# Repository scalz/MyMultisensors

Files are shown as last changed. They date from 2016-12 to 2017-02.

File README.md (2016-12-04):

# MyMultisensors

MyMultisensors is a compact multi sensors capable node for your/my home automation.
Optmized for very low power, ambiant sensors node, battery powered and wireless, i can easily add in each room. 

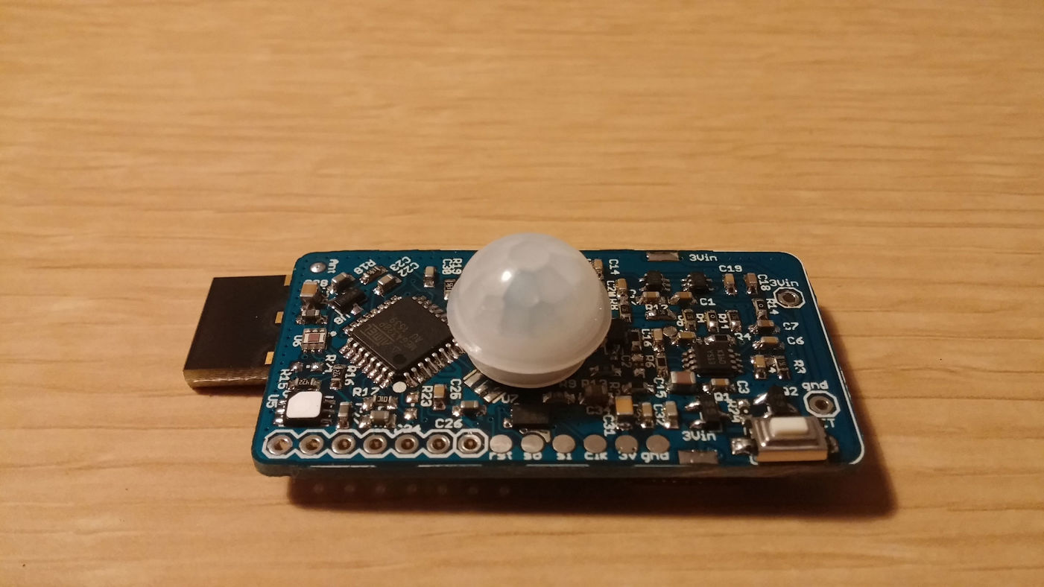
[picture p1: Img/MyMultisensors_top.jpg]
MyMultisensors top
 

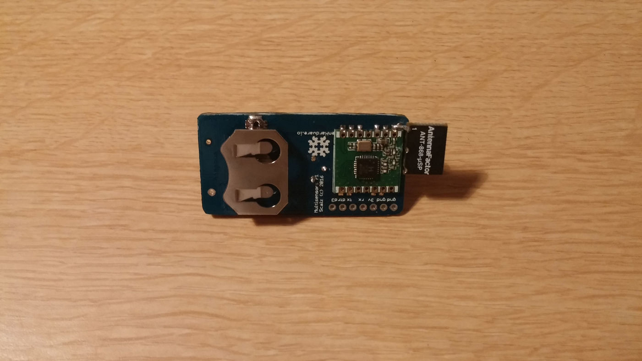
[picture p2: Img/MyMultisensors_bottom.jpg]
MyMultisensors bottom
 

I have to say, this is one of my favorite board! well, you think i'm biased :) a bit true ;)
But the truth is i've never seen the same board before (with my requirements) or i wouldn't have made it!

I put multiple "constraints" on myself to get the best of what i can do myself imho.
- Most common sensors used indoor : Temperature/Humidity/Motion/Ambiant Light/Door Contact. Using the best low power sensors i know.
- Entry level MCU so noobs can easily play with it (well known 328p)
- Tiny so i can reuse the board if i need a simple motion or door contact device. One pcb allows multiple devices. Standardisation of main ambiant indoor devices with box.
- Thin, like a simple temperature/humidity tag. So coincell 2032. Depending on the scenario, I need to be able to change the battery holder for CR2032/CR2450/AAA.
- Very very low power. 2years min with a simple good brand CR2032 (depending of usecase). Choosing the right parts for low power.
- Mysensors Wireless programming and Signing/Authentication features are mandatory for a device which can do some security tasks like Motion detection.
- RFM69 and its nice range even with the low power RFM69CW version onboard. I'm finalizing the nrf24 version because it's a nice board, that would be too bad for nrf24 user ;)
- I also tried to take care of the routing; and to have strong, unbroken GND plane as it is very important to get best range, especially with monopole wire I'm using (it's also possible to use a planar pcb ant though) 
- and not the least constraint! I've tried to keep cost reasonable regarding if i would buy it, or people etc..

As everything is customizable, the choice of the battery or the custom pcb size (compact), the easy and quite common way is printing a custom box..

I think i've "almost" achieved my goals :)

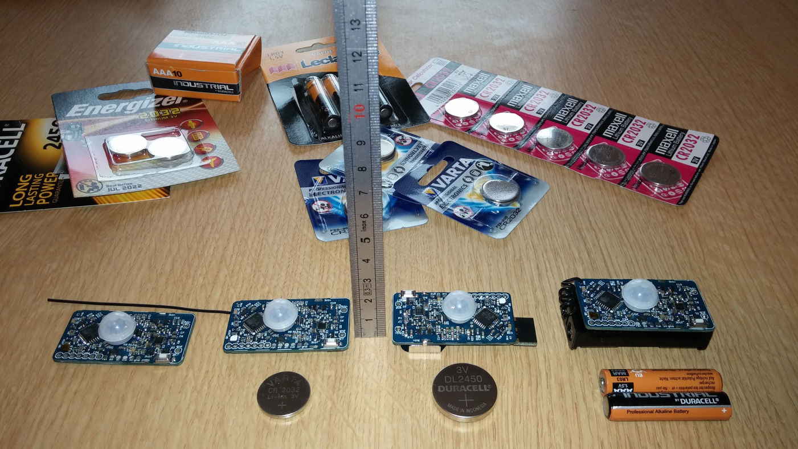
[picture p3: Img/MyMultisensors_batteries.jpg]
MyMultisensors batteries
 

We can see this is possible to use different kind of battery, and different antennas (wire or planar pcb).

###General specs
------

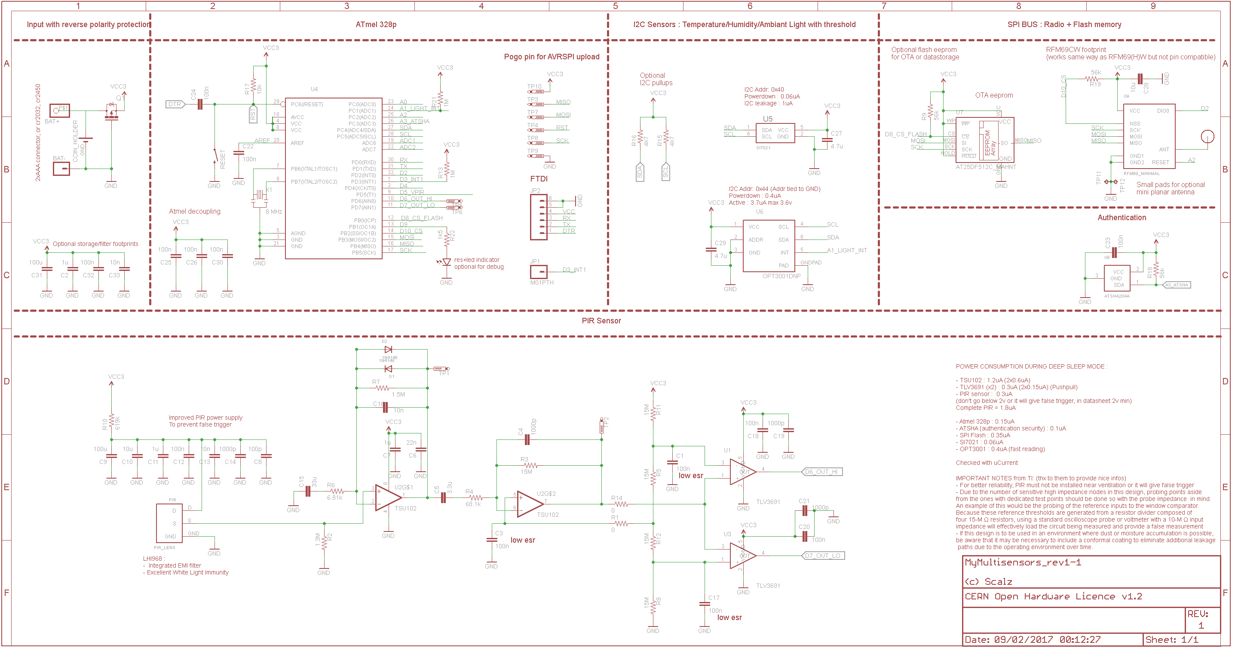
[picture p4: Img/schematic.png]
schematic
 

|Specs|  |
|---|---|---|
|Size |49*25.4 (mm) |
| MCU | Atmel328p TQFP 150nA deep sleep|
| Radio | RFM69CW 100nA in deep sleep, NRF24 is coming |
| Authentication security | ATSHA204A chip footprint 150nA in deep sleep|
| OverTheAir Wireless programming | SPI flash eeprom footprint 200nA in deep sleep |
| Temperature/Humidity | SI7021 60nA in deep sleep |
| Ambiant Light Lux | OPT3001 300nA in deep sleep, with footprint for optional pullup resistor |
| Motion detection | LHI968 good quality/price, with its circuit, active 1.6uA |
| Door contact | footprint for soldering an optional pullup resistor >1M | 
| Indicator Led | Yes, on D9 |
| Extension connector | FTDI + D3 for connecting Door contact | 
| Pogo pins | AVRSPI programming |
| Battery connectors | CR2032 240mAh, CR2450 500mAh, 2xAAA 1200mAh |
| Power Supply | Reverse-polarity protection. 3V3 max |

####Onboard safety

Onboard, there is a reverse polarity protection. But for power savings, better efficiency etc .. there is no voltage regulator. So it's possible to use others batteries, or ftdi of course, but the max input voltage is 3.3V max.

####Extension Connectors

For simplicity, and trying to boost my assembling process (i use reflow), i'm using pogopins. I've done a simple adapter like this..
- AVRSPI : for burning the bootloader. Here i'm using the Sensebender Micro Atmel 328p Internal 8Mhz BOD 1.8V, in Boards Manager/Mysensors boards
- FTDI : for uploading the sketch. Without an optimized sketch, no big power savings. it's hw/sw.. still work in progress, i'll never be happy :)

####Power consumption, what can we expect ?

Power consumption has been checked with uCurrent Gold + old voltcraft vc506..

Measurement done with PIR enabled, sensors sleeping but without spiflash ic nor Door contact

| Mode | Varta coincell CR2032 | Duracell 2xAAA |
|---|---|---|---|
|MCU in deep sleep, interrupt on change |4uA | 3uA|
|MCU in deep sleep, interrupt on change Wdt Enabled | 8uA | 11uA|
|MCU running 1Mhz | 732uA | 737uA|

Few simple maths because battery lifetime can change for multiple reasons (battery brand, internal resistance of coincell etc.). I won't explain everything here.

Still important to remember, is we can't expect to have the complete 240mAh of a coincell. Better bet on 200mAh, for a good quality coincell. For bad quality, it can be worse! Bad clone coincell can have only 50% of usable energy! Try clone and good brands, you will see what i mean ;) it's up to you if you want to spend your time to replace batteries :)

As RFM69 radio power consumption is low during sleep mode, no need to disable it, so it allows to use listenmode and wakeup from mcu from deep sleep for instance.

Say a power consumption of 5uA during sleep mode, the PIR is enabled of course, but not triggered (note it is possible to disable the PIR motion sensor to save power).
And our RFM69 needs 30mA during 40ms. Rough estimation!  it does not spend this whole 40ms transmitting of course! And with automatic RSSI and power level control, the radio can consumes less power in TX.
On other hand, it does not take in account the signing time if feature is used.

So 30mA for 40ms, say 10 motions detection/hour, give us a theoretical estimation of 2.33years.
Not so bad..but the node can last a lot more if the software is well optimized and flexible to let user to set dynamically during days, the sensibility and motion detection settings etc..

####Arduino Pin description

|Arduino sketch define| Arduino Pin | description |
|---|---|---|
| MY_OTA_FLASH_SS | 8 | EEprom CS pin |
| ATSHA204_PIN | 17 | ATSHA204A SOT23 pin (for authentication) |
| PIR_INT_PINH  | 6 | PIR motion sensor pin H |
| PIR_INT_PINL | 7 | PIR motion sensor pin L |
| MYNODE_LED_PIN | 9 | Status led pin |
| REED_SWITCH_PIN | 3 | Reed switch pin interrupt on int1 D3 |
| AMBIANT_LIGHT_INT | A1  | Ambiant light sensor pin interrupt |

### Some ideas for the Mysensors sketch
------

|General Node settings | Default Settings | Notes|
|---|---|---|---|
| MY_NODE_NAME | MYS_MOTION| Node/sketch name|
|MY_DEBUG|1.0| General Level Mysensors Debug messages. Comment it to save memory!|
|MY_DEBUG_SKETCH|1.0|Sketch Level Debug messages. Comment it to save memory!|
|MY_NODE_ID|AUTO| AUTO or set a fixed ID|
|PARENT_NODE_ID|| Uncomment it and set your parent node id if needed|
|RELEASE |1.0| Sketch version|
|MY_BAUD_RATE|38400||
|isMetric |true| true/false|
|//atsha204Class sha204(sha204Pin);||Uncomment to enable signing|
|//MY_OTA_FIRMWARE_FEATURE||Uncomment to enable OTA wireless programming|
|MY_RFM69_NETWORKID|100| Uncomment and set your preferred network id|
|MY_RFM69_ATC_TARGET_RSSI_DBM|-80| Uncomment and set your preferred RSSI target|
|LIGHT_H_LIMIT|100|High Threshold for Ambiant light sensor|
|LIGHT_L_LIMIT|20|Low Threshold for Ambiant light sensor|
|LIGHT_TRANSMIT_THRESHOLD|50| Delta needed for updating Ambiant sensor to controller|
|HUMI_TRANSMIT_THRESHOLD|5|Delta needed for updating Humidity sensor to controller|
|TEMP_TRANSMIT_THRESHOLD|1|Delta needed for updating Temperature sensor to controller|
|FORCE_TRANSMIT_INTERVAL|10| Intervalle time between transmit update|
|BATTERY_USB| |Uncomment if using ftdi, for batt voltage reading|
|BATTERY_VARTA_2032| |Uncomment if using CR2032, for batt voltage reading|
|BATTERY_DURAC_2450| |Uncomment if using CR2450, for batt voltage reading|
|BATTERY_DURAC_IND_2AAA| |Uncomment if using 2xAAA, for batt voltage reading|

|MyPirHelper.h | Default Settings | Notes |
|---|---|---|---|
| PIR_SETTLE_TIME | 20000| in milliseconds/ better 30000. Waiting for PIR settling at node init|
| PIR_DEFAULT_PULSES | 8| Programmable pulse counter : 1... 255 pulses but for 255 pulses you'll need to dance for a nice motion :)|
| PIR_DEFAULT_WINDOWTIME | 1| Window time : 0 to 3.  Range: 8s... 16s.  Time in sec = 8 * (value+1)|
| PIR_DEFAULT_CANCELTIME | 2| Cancel Time : 0 to 10. Range: 8s... 80s.  Time = 8 * (value+1)|
| PIR_DEFAULT_BLINDTIME | 2| Blind Time  : 0 to 15. Range: 0s... 120s. Time = 8 * value|

All these infos can be found in the source files.

####External Libraries needed
- Opt3001      : https://github.com/node-it/EnvironOne/blob/master/src/Opt3001.h
- SI7021       : from Marcus Sorensen <marcus@electron14.com> 

####From the controller view

These are the CHILD_IDs used for sensors, or for dynamic settings.

|CHILD NODE ID/CMD | Default ID | Notes|
|---|---|---|---|
| CHILD_ID_PIR | 1|PIR sensor |
| CHILD_ID_PIR_EN | 2|Enable PIR |
| CHILD_ID_TEMP  | 3|Temperature sensor|
| CHILD_ID_HUM | 4|Humidity Child node ID|
| CHILD_ID_LIGHT  | 5|Ambiant light Child node ID|
| CHILD_ID_DOOR | 6|Door reed switch|
| CMID_FULL | 10|Command from controller with all params below in one tx. below is for debug..|
| CMID_PULSES | 11|Command from controller to set PIR number of pulse for windows time  |
| CMID_WINDOWTIME | 12|Command from controller to set PIR window time  |
| CMID_BLINDTIME | 13|Command from controller to set PIR blind time|
| CMID_CANCELTIME | 14|Command from controller to set PIR cancel time|
| CMID_EN_LIGHT | 15|Command from controller to enable Light sensor threshold|
| CMID_LIGHT_MODE | 16|Command from controller to set Light sensor special mode (enable pir at certain light level only...)|
| CMID_LIGHT_H  | 17|Command from controller to set Light sensor high threshold |
| CMID_LIGHT_L | 18|Command from controller to set Light sensor low threshold |
| CMID_LIGHT_DELTA | 19|Command from controller to set difference of lux for update controller |
| CMID_TRANSMIT_INTERVAL | 20|Command from controller to set time between sensor updates|
| CMID_TH_DELTA | 21|Command from controller to set difference of temp/hum needed for update controller |
| CMID_EN_LED  | 22|Command from controller to set led|

###Known issues
------ 

###TODO
------
- improve sketch

###Donations
------

I'm trying to make opensource projects. I do this for free and sharing spirit. I don't do ads etc..
But if you think information here is worth of some money, or want to reward me, feel free to send any amount through paypal.

  

Or you can also order pcb here :
I will earn a little percentage that will allow me to order proto pcb and share more fun design.

Or pay me a protein smoothie if you see me! oh well, a beer is ok too :)

### Contributors
------
Always special thanks to:
- Mysensors Team for its great work
- Adafruit, Sparkfun, TI, Atmel etc.. for all educational infos they share

###Links, reference and license** 
------
- https://www.openhardware.io/view/75/MyMultisensors
- http://www2.st.com/content/ccc/resource/technical/document/application_note/b8/84/29/41/21/00/44/41/DM00096551.pdf/files/DM00096551.pdf/jcr:content/translations/en.D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
- http://www.ti.com/lit/ug/tiduau1a/tiduau1a.pdf

Copyright Scalz (2016). released under the CERN Open Hardware Licence v1.2

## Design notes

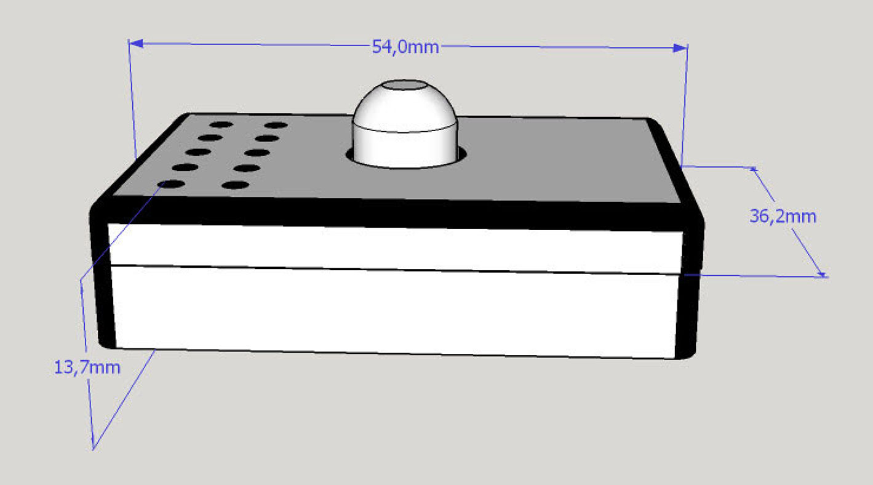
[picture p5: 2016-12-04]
Img/MyMultisensors_custombox_temp.jpg

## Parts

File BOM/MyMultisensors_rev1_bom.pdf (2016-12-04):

Parts | Qty Don't Put
Opt

Value

C1, C3, C12, C17, C18, C20, C22, C23, C25, C26 | 10 | | 100n
C30, C32, C33 | 12 | X
C4, C14, C19, C21 | 4 | | 1000p
C5 | 1 | | 3.3u
C6 | 1 | | 22n
C7, C11 | 2 | | 1u
C8 | 1 | | 100p
C13, C16 | 2 | | 10n
C27, C29 | 2 | | 4.7u
C2 | 1 | | 1u
C24 | 1 | | 100n
C9, C31 | 2 | | 100u
C10, C28 | 2 | | 10u
C15 | 1 | | 33u
D1, D2 | 2 | | 1N4148
D3 | 1 | | Red LED
Q1 | 1 | | CJ2305
R1, R14 | 2 | | 0
R2 | 1 | | 1.3M
R3, R5, R8, R11, R12 | 5 | | 15M
R4 | 1 | | 68.1k
R6 | 1 | | 6.81k
R7 | 1 | | 1.5M
R9, R18, R19 | 3 | | 56k
R10 | 1 | | 619k
R13, R21 | 2 | X | 1M
R15, R16 | 2 | | 4k7
R22 | 1 | | 1k5
R17 | 1 | | 10k
U1, U3 | 2 | | TLV3691IDCKR
U2 | 1 | | TSU102IST
U4 | 1 | | ATMEGA328P-AU
U5 | 1 | | SI7021-A20-GM1
U6 | 1 | | OPT3001DNPR
U7 | 1 | | AT25DF512C-MAHN-T
U8 | 1 | | ATSHA204A-STUCZ-T
U9 | 1 | | RFM69CW
RESET | 1 | | 1101NE
PIR | 1 | | LHI968
X1 | 1 | | 8 MHz
COIN_HOLDER | 1
JP2 | 1

Notes about optional parts:
- Some capa are optional. Footprints is there. For stability or more buffer.
- Resistors are for optional Reedswitch and optional Lux sensor Thresholds. Solder them if needed only or power consumption can increase

Package | Description | MPN
0603 | Capacitor
0603 | Capacitor
0603 | Capacitor
0603 | Capacitor
0603 | Capacitor
0603 | Capacitor
0603 | Capacitor
0603 | Capacitor
0603 | Capacitor
0805 | Capacitor
0805 | Capacitor
0805 | Capacitor
0805 | Capacitor
0805 | Capacitor
SOD-123 | Diode
0805 | LED
SOT23-3 | P-Channel MOSFET
0603 | Resistor
0603 | Resistor
0603 | Resistor
0603 | Resistor
0603 | Resistor
0603 | Resistor
0603 | Resistor
0603 | Resistor
0603 | Resistor
0603 | Resistor
0603 | Resistor
0805 | Resistor
SC70-5 | Comparator | 595-TLV3691IDCKR
MINI_SO8 | Dual Opamp | 511-TSU102IST (http://www.mouser.fr/ProductDetail/STMicroelectronics/TSU102IST/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)
TQFP32 | Atmel 8bit 328P TQFP32
DFN6 | Temp/Hum sensor | 634-SI7021-A20-GM1
OPT3001DNP | Lux sensor | 595-OPT3001DNPR
AT25DF512C_MAHNT SPI Flash | 988-AT25DF512CMAHN-T
SOT23-3 | Signing IC | 566-ATSHA204ASTUCZ-T
RFM69CW | Hoperf radio
| Tactile Switch 1101NE
TO5 | PIR sensor
RESONATOR-SMD | Resonator
Coincell Holder | CR2032/2450 footprints
1X06 | Pinheader

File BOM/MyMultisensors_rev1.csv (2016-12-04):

Parts | Qty | Don't Put Opt | Value | Package | Description | MPN
C1, C3, C12, C17, C18, C20, C22, C23, C25, C26 | 10 |  | 100n | 0603 | Capacitor
C30, C32, C33 | 12 | X |  | 0603 | Capacitor
C4, C14, C19, C21 | 4 |  | 1000p | 0603 | Capacitor
C5 | 1 |  | 3.3u | 0603 | Capacitor
C6 | 1 |  | 22n | 0603 | Capacitor
C7, C11 | 2 |  | 1u | 0603 | Capacitor
C8 | 1 |  | 100p | 0603 | Capacitor
C13, C16 | 2 |  | 10n | 0603 | Capacitor
C27, C29 | 2 |  | 4.7u | 0603 | Capacitor
C2 | 1 |  | 1u | 0805 | Capacitor
C24 | 1 |  | 100n | 0805 | Capacitor
C9, C31 | 2 |  | 100u | 0805 | Capacitor
C10, C28 | 2 |  | 10u | 0805 | Capacitor
C15 | 1 |  | 33u | 0805 | Capacitor
D1, D2 | 2 |  | 1N4148 | SOD-123 | Diode
D3 | 1 |  | Red LED | 0805 | LED
Q1 | 1 |  | CJ2305 | SOT23-3 | P-Channel MOSFET
R1, R14 | 2 |  | 0 | 0603 | Resistor
R2 | 1 |  | 1.3M | 0603 | Resistor
R3, R5, R8, R11, R12 | 5 |  | 15M | 0603 | Resistor
R4 | 1 |  | 68.1k | 0603 | Resistor
R6 | 1 |  | 6.81k | 0603 | Resistor
R7 | 1 |  | 1.5M | 0603 | Resistor
R9, R18, R19 | 3 |  | 56k | 0603 | Resistor
R10 | 1 |  | 619k | 0603 | Resistor
R13, R21 | 2 | X | 1M | 0603 | Resistor
R15, R16 | 2 |  | 4k7 | 0603 | Resistor
R22 | 1 |  | 1k5 | 0603 | Resistor
R17 | 1 |  | 10k | 0805 | Resistor
U1, U3 | 2 |  | TLV3691IDCKR | SC70-5 | Comparator | 595-TLV3691IDCKR
U2 | 1 |  | TSU102IST | MINI_SO8 | Dual Opamp | 511-TSU102IST
U4 | 1 |  | ATMEGA328P-AU | TQFP32 | Atmel 8bit 328P TQFP32
U5 | 1 |  | SI7021-A20-GM1 | DFN6 | Temp/Hum sensor | 634-SI7021-A20-GM1
U6 | 1 |  | OPT3001DNPR | OPT3001DNP | Lux sensor | 595-OPT3001DNPR
U7 | 1 |  | AT25DF512C-MAHN-T | AT25DF512C_MAHNT | SPI Flash | 988-AT25DF512CMAHN-T
U8 | 1 |  | ATSHA204A-STUCZ-T | SOT23-3 | Signing IC | 566-ATSHA204ASTUCZ-T
U9 | 1 |  | RFM69CW | RFM69CW | Hoperf radio
RESET | 1 |  | 1101NE |  | Tactile Switch 1101NE
PIR | 1 |  | LHI968 | TO5 | PIR sensor
X1 | 1 |  | 8 MHz | RESONATOR-SMD | Resonator
COIN_HOLDER | 1 |  |  | Coincell Holder | CR2032/2450 footprints
JP2 | 1 |  |  | 1X06 | Pinheader
Notes about optional parts: - Some capa are optional. Footprints is there. For stability or more buffer. - Resistors are for optional Reedswitch and optional Lux sensor Thresholds. Solder them if needed only or power consumption can increase

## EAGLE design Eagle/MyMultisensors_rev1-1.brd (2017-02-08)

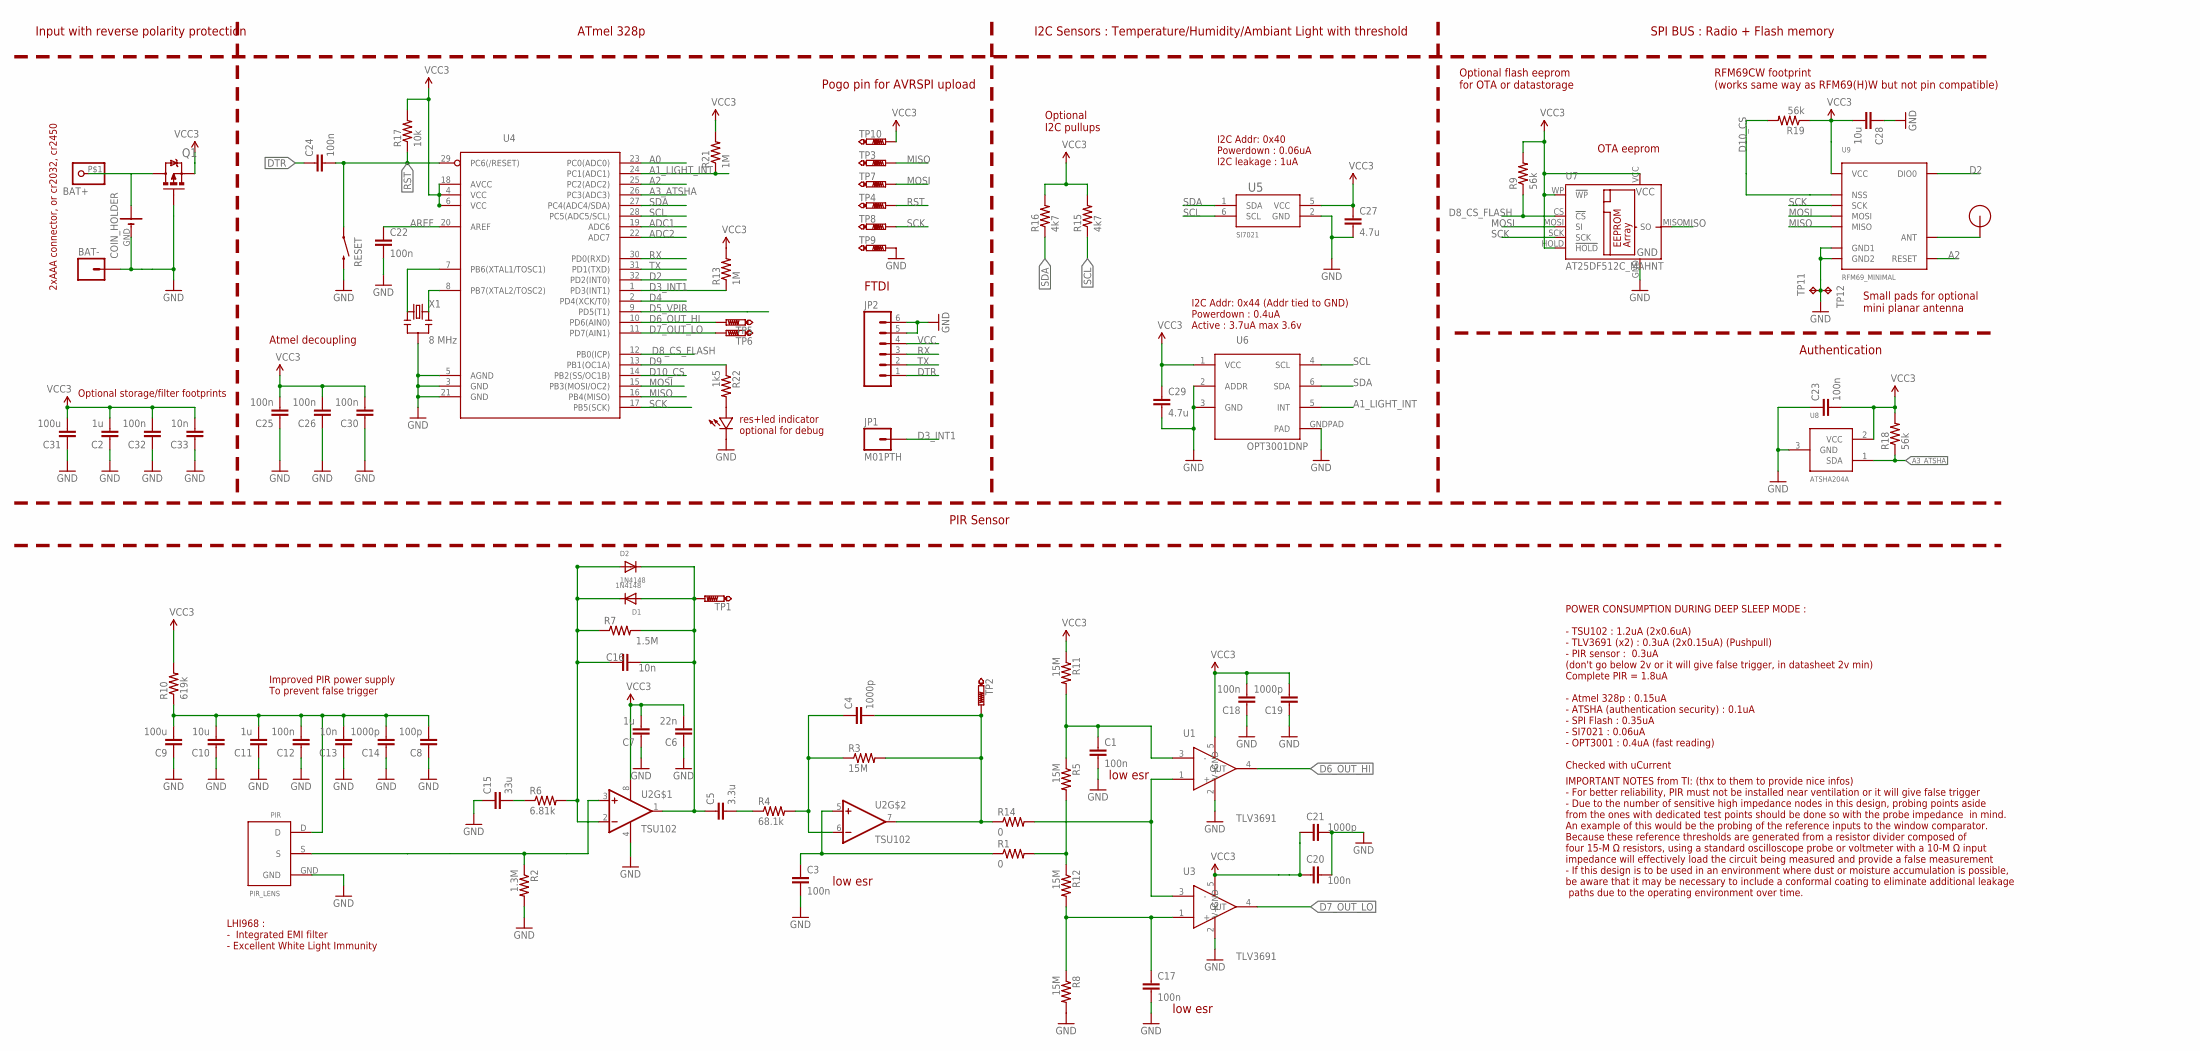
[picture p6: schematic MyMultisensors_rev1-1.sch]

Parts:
ANT: RFM12B_ANTENNA; RFM12B-ANTENNA
BAT+: PINHD-1X1TOP; 1X01_ONESIDE
BAT-: M01PTH; 1X01
C1, C3, C12, C17, C18, C20, C22, C23, C25, C26, C30, C32: 100n; 0603-CAP
C2: 1u; 0805-CAP
C4, C14, C19, C21: 1000p; 0603-CAP
C5: 3.3u; 0603-CAP
C6: 22n; 0603-CAP
C7, C11: 1u; 0603-CAP
C8: 100p; 0603-CAP
C9, C31: 100u; 0805-CAP
C10, C28: 10u; 0805-CAP
C13, C16, C33: 10n; 0603-CAP
C15: 33u; 0805-CAP
C24: 100n; 0805-CAP
C27, C29: 4.7u; 0603-CAP
COIN_HOLDER: CR2450_H_LOWCOSTVERTICAL_WITH_MILL; CR2450H_LOWCOST2
D1, D2: 1N4148; SOD-123
D3: LED0805; 0805-LED
JP1: M01PTH; 1X01
JP2: M06SIP; 1X06
PIR: PIR_LENS
Q1: SI2399DS-T1-GE3; SOT95P237X112-3N
R1, R14: 0; 0603-RES
R2: 1.3M; 0603-RES
R3, R5, R8, R11, R12: 15M; 0603-RES
R4: 68.1k; 0603-RES
R6: 6.81k; 0603-RES
R7: 1.5M; 0603-RES
R9, R18, R19: 56k; 0603-RES
R10: 619k; 0603-RES
R13, R21: 1M; 0603-RES
R15, R16: 4k7; 0603-RES
R17: 10k; 0805-RES
R22: 1k5; 0603-RES
RESET: SWITCH-MOMENTARY-2-SMD-1101NE; TACTILE-SWITCH-1101NE
TP1, TP2, TP5, TP6: PTR1B1,27; B1,27
TP3, TP4, TP7, TP8, TP9, TP10: PTR1TP18R; TP18R
TP11, TP12: TPTP10SQ; TP10SQ
U1, U3: TLV3691; SC70-5
U2: TSU102; MINI_SO8
U4: ATMega-328; TQFP32-08
U5: SI7021; DFN6
U6: OPT3001DNP
U7: AT25DF512C_MAHNT
U8: ATSHA204A; SOT23
U9: RFM69_MINIMAL; RFM69CW_MINIMAL
X1: 8 MHz; RESONATOR-SMD

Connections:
A0: U4.23 (PC0(ADC0))
A1_LIGHT_INT: R21.1, U4.24 (PC1(ADC1)), U6.5 (INT)
A2: U4.25 (PC2(ADC2)), U9.RESET
A3_ATSHA: R18.1, U4.26 (PC3(ADC3)), U8.1 (SDA)
ADC1: U4.19 (ADC6)
ADC2: U4.22 (ADC7)
AREF: C22.1, U4.20 (AREF)
D2: U4.32 (PD2(INT0)), U9.DIO0
D3_INT1: JP1.1, R13.1, U4.1 (PD3(INT1))
D4: U4.2 (PD4(XCK/T0))
D5_VPIR: U4.9 (PD5(T1))
D6_OUT_HI: TP5.TP, U1.4 (OUT), U4.10 (PD6(AIN0))
D7_OUT_LO: TP6.TP, U3.4 (OUT), U4.11 (PD7(AIN1))
D8_CS_FLASH: R9.1, U4.12 (PB0(ICP)), U7.CS (!CS)
D9: R22.1, U4.13 (PB1(OC1A))
D10_CS: R19.2, U4.14 (PB2(SS/OC1B)), U9.NSS
DTR: C24.1, JP2.1
GND: BAT-.1, C1.2, C2.1, C3.2, C6.1, C7.1, C8.1, C9.1, C10.1, C11.1, C12.1, C13.1, C14.1, C15.1, C17.2, C18.1, C19.1, C20.1, C21.1, C22.2, C23.1, C25.1, C26.1, C27.2, C28.1, C29.2, C30.1, C31.1, C32.1, C33.1, COIN_HOLDER.GND (-), D3.MINUS, JP2.5, JP2.6, PIR.GND, Q1.1 (G), R2.2, R8.2, RESET.P$2 (2), TP9.TP, TP11.TP, TP12.TP, U1.2 (GND), U2.4 (V-), U3.2 (GND), U4.3 (GND), U4.5 (AGND), U4.21 (GND), U5.2 (GND), U6.2 (ADDR), U6.3 (GND), U6.GNDPAD (PAD), U7.GND, U8.3 (GND), U9.GND (GND1), U9.GND2, X1.2
MISO: TP3.TP, U4.16 (PB4(MISO)), U7.MISO (SO), U9.MISO
MOSI: TP7.TP, U4.15 (PB3(MOSI/OC2)), U7.MOSI (SI), U9.MOSI
unnamed: C17.1, R8.1, R12.2, U3.1 (+)
unnamed: PIR.S, R2.1, U2.3 (+IN)
unnamed: D3.PLUS, R22.2
unnamed: C16.1, D1.C, D2.A, R6.2, R7.1, U2.2 (-IN)
unnamed: C15.2, R6.1
unnamed: C5.1, C16.2, D1.A, D2.C, R7.2, TP1.TP, U2.1 (OUT)
unnamed: C5.2, R4.1
unnamed: C4.1, R3.1, R4.2, U2.6 (-IN)
unnamed: C4.2, R3.2, R14.1, TP2.TP, U2.7 (OUT)
unnamed: U4.7 (PB6(XTAL1/TOSC1)), X1.1
unnamed: C1.1, R5.1, R11.2, U1.3 (-)
unnamed: C3.1, R1.1, U2.5 (+IN)
unnamed: C8.2, C9.2, C10.2, C11.2, C12.2, C13.2, C14.2, PIR.D, R10.1
unnamed: R14.2, U1.1 (+), U3.3 (-)
unnamed: R1.2, R5.2, R12.1
unnamed: U4.8 (PB7(XTAL2/TOSC2)), X1.3
unnamed: ANT.P$1, U9.ANT
unnamed: BAT+.P$1, COIN_HOLDER.VBAT@1 (+), COIN_HOLDER.VBAT@2 (+), COIN_HOLDER.VBAT@3 (+), COIN_HOLDER.VBAT@4 (+), Q1.3 (D)
RST: C24.2, R17.1, RESET.P$1 (1), TP4.TP, U4.29 (PC6(/RESET))
RX: JP2.3, U4.30 (PD0(RXD))
SCK: TP8.TP, U4.17 (PB5(SCK)), U7.SCK, U9.SCK
SCL: R15.1, U4.28 (PC5(ADC5/SCL)), U5.6 (SCL), U6.4 (SCL)
SDA: R16.1, U4.27 (PC4(ADC4/SDA)), U5.1 (SDA), U6.6 (SDA)
TX: JP2.2, U4.31 (PD1(TXD))
VCC: C2.2, C6.2, C7.2, C18.2, C19.2, C20.2, C21.2, C23.2, C25.2, C26.2, C27.1, C28.2, C29.1, C30.2, C31.2, C32.2, C33.2, JP2.4, Q1.2 (S), R9.2, R10.2, R11.1, R13.2, R15.2, R16.2, R17.2, R18.2, R19.1, R21.2, TP10.TP, U1.5 (V+), U2.8 (V+), U3.5 (V+), U4.4 (VCC), U4.6 (VCC), U4.18 (AVCC), U5.5 (VCC), U6.1 (VCC), U7.HOLD (!HOLD), U7.VCC, U7.WP (!WP), U8.2 (VCC), U9.VDD (VCC)

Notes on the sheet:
IMPORTANT NOTES from TI: (thx to them to provide nice infos) - For better reliability, PIR must not be installed near ventilation or it will give false trigger - Due to the number of sensitive high impedance nodes in this design, probing points aside from the ones with dedicated test points should 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
POWER CONSUMPTION DURING DEEP SLEEP MODE : - TSU102 : 1.2uA (2x0.6uA) - TLV3691 (x2) : 0.3uA (2x0.15uA) (Pushpull) - PIR sensor : 0.3uA (don't go below 2v or it will give false trigger, in datasheet 2v min) Complete PIR = 1.8uA - Atmel 328p : 0.15uA - ATSHA (authentication security) : 0.1uA - SPI F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
LHI968 : - Integrated EMI filter - Excellent White Light Immunity
Optional I2C pullups
I2C Addr: 0x40 Powerdown : 0.06uA I2C leakage : 1uA
I2C Addr: 0x44 (Addr tied to GND) Powerdown : 0.4uA Active : 3.7uA max 3.6v
RFM69CW footprint (works same way as RFM69(H)W but not pin compatible)
Atmel decoupling
res+led indicator optional for debug
PIR Sensor
I2C Sensors : Temperature/Humidity/Ambiant Light with threshold
ATmel 328p
Input with reverse polarity protection
SPI BUS : Radio + Flash memory
Authentication
Optional storage/filter footprints
2xAAA connector, or cr2032, cr2450
Improved PIR power supply To prevent false trigger
low esr
OTA eeprom
Pogo pin for AVRSPI upload
FTDI
Small pads for optional mini planar antenna
Optional flash eeprom for OTA or datastorage

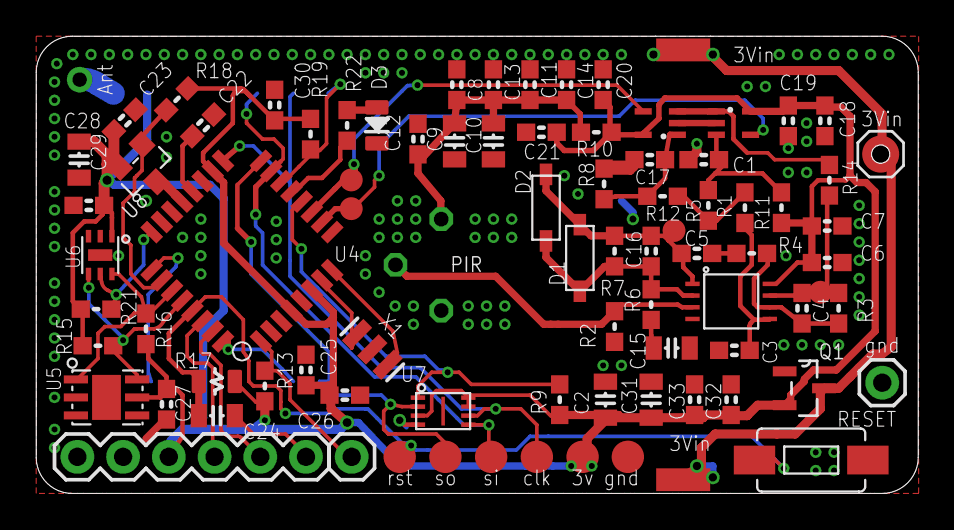
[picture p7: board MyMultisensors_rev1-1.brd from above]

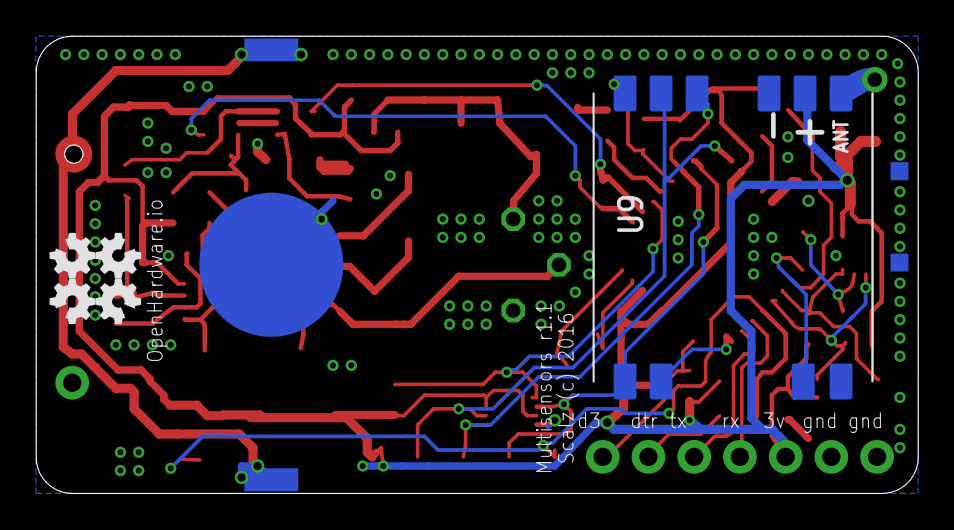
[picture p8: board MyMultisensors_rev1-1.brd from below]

Board: 2 copper layers, 49.0 x 25.4 mm, 89 parts (5 on the bottom side), 40 nets.

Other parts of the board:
U$6: OPENHW_IO_SMALL

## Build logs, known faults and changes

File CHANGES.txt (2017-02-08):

Febr. 9 2017 (Scalz)
  MyMultisensors Revision 1.1
	- Fixed reverse polarity protection 
	  Drain and source was inverted on Q1 for revision 1.0 powering through mosfet diode (0.6V) when polarity was crossed
		Thanks to @Koresh for feedback
		
Dec. 4 2016 (Scalz):
    MyMultisensors Revision 1
	
    Features:
		- Size 	49*25.4 (mm) 
		- MCU 	Atmel328p TQFP 150nA deep sleep
		- Radio 	RFM69CW 100nA in deep sleep, NRF24 is coming
		- Authentication security 	ATSHA204A chip footprint 150nA in deep sleep
		- OverTheAir Wireless programming 	SPI flash eeprom footprint 200nA in deep sleep
		- Temperature/Humidity 	SI7021 60nA in deep sleep
		- Ambiant Light Lux 	OPT3001 300nA in deep sleep, with footprint for optional pullup resistor
		- Motion detection 	LHI968 good quality/price, with its circuit, active 1.6uA
		- Door contact 	footprint for soldering an optional pullup resistor >1M
		- Indicator Led 	Yes, on D9
		- Extension connector 	FTDI + D3 for connecting Door contact
		- Pogo pins 	AVRSPI programming
		- Battery connectors 	CR2032 240mAh, CR2450 500mAh, 2xAAA 1200mAh
		- Power Supply 	Reverse-polarity protection. 3V3 max

    Known issues:

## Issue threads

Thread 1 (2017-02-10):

Buyable?

TehEbil, 2017-02-10:
Hey, sorry, I didn't know how to contact you, so:
I'd like to ask if one can buy that device as it is and how much it would cost?

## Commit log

2016-12-04 update desc and design files
    [MyMultisensors_rev1.GBL, MyMultisensors_rev1.GBO, MyMultisensors_rev1.GBP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]
2017-02-08 Reverse polarity protection fixed
    Drain and source was inverted on Q1 for revision 1.0 powering through
    mosfet diode (0.6V) when polarity was crossed.
    [MyMultisensors_rev1-1.GBL, MyMultisensors_rev1-1.GBO, MyMultisensors_rev1-1.GBP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]

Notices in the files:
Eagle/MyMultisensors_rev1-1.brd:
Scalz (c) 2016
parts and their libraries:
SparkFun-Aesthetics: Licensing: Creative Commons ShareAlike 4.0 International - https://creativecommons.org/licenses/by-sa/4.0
